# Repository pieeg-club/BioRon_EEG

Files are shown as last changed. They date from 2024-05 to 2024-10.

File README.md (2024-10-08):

# Open-source active electrode for biodata measurement of EEG, EMG,  etc. BioRon_EEG from PiEEG

<p align="center">
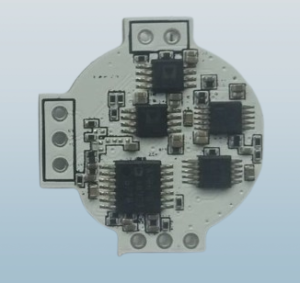
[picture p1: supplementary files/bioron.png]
generals view
  
</p>

### Low noise power supply, 2 stage Amplifier, Driven Right Leg, Band-Pass Filter, and ADC in one small board       

Our project aims to democratize the field of electroencephalography (EEG) by developing and sharing open-source designs for active EEG electrodes. EEG is a powerful technique for monitoring brain activity, but the cost and complexity of traditional EEG equipment have limited its accessibility. We're here to change that!  
 
Our repository hosts detailed schematics, and layouts for creating active EEG electrodes. Whether you're a hardware enthusiast or a researcher, you can find everything you need to build your own electrodes from scratch.  

### Contributing:       
Whether you're an electronics wizard, a software guru, a neuroscience enthusiast, or just curious, your contributions are welcome! 

### Our Vision:      
By providing open-source active EEG electrode designs, we're fostering collaboration, innovation, and knowledge sharing in the fields of neuroscience, bioengineering, and beyond. Our goal is to make high-quality EEG technology accessible to researchers, students, hobbyists, and clinicians worldwide, enabling a deeper understanding of the human brain and its functions. 

Join us in PiEEG mission to revolutionize EEG technology and make a significant impact on brain research! Feel free to reach out, contribute, and be part of the EEG revolution. 

### Contact:
Email: pieeg@pieeg.com  
Website: https://pieeg.com/    

Paper    
https://www.preprints.org/manuscript/202409.1703/v1    
Cite as: 
rakhmatulin, I. A Novel Tiny Open-Source Board BioRon_EEG for Dry Active Electrode. Preprints 2024, 2024091703. https://doi.org/10.20944/preprints202409.1703.v1

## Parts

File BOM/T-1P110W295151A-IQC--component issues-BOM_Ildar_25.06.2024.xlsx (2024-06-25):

T-1P110W295151A-BOM清单
No. Item | 捷创ID | 型号 Mfg Part | 封装 Package/Footprint | 规格参数 Description / Value | 位号 Designator | 单板用量 Qty per board | 总量 Total Qty | 来料数量 Qty Received | 物料备注 Instructions / Notes | 不良原因 Assembly Question | 是否全部空贴 | 是否少料空贴 | 是否按来料贴 | 是否等补料 | 客户回复 Reply from Customer
1 | W202830-001 | ADS1115IDGSR |  | ADS1115IDGSR | U1.ads1115 | 1 | 1 | 1
2 | W202830-002 | ad8618ad2086429 https://www.mouser.co.uk/ProductDetail/Analog-Devices/AD8618ARUZ-REEL?qs=%2FtpEQrCGXCyqKNk0uxY9fw%3D%3D | SOP65P640X120-14N |  | U2.ad8618 | 1 | 1 | 1 |  | As shown in picture, component is bigger than pads on the board. It can't be soldered. Please check and reply. Repalce for ad8618ad2086429
3 | W202830-003 | AD8220WARMZ |  | AD8220WARMZ | U3.AD8220 | 1 | 1 | 1
4 | W202830-004 | OPA2320SAIDGSR | SOP50P490X110-10N |  | U4.OPA-2320 | 1 | 1 | 1 |  | As shown in picture, component is bigger than pads on the board. It can't be soldered. Please check and reply. Replace for OPA2320SAIDGSR
5 | W202830-005 | OP2177ARMZ-R7 | MSOP-8 |  | U5.OP2177 | 1 | 1 | 1 |  | As shown in picture, component is bigger than pads on the board. It can't be soldered. Please check and reply. Replace for OP2177ARMZ-R7
6 | W202830-006 | LT3042IMSE#PBF | MSOP-10 |  | U1.1 | 1 | 1 | 1 |  | As shown in picture, component is bigger than pads on the board. It can't be soldered. And there is no pad in the center on the board. Please check and reply. Replace for LT3042IMSE#PBF
7 | W202830-007 | LM2662MX/NOPB |  | LM2662M | U1.2 | 1 | 1 | 1 |  | As shown in picture, component is bigger than pads on the board. It can't be soldered. Please check and reply.
8 | W202830-008 | LT3094IMSE#PBF |  | LT3094IMSE#PBF | U1.3 | 1 | 1 | 1 |  | As shown in attached screenshot, there is no pad on the board in thecenter .Should we solder what we received? Yes, please solder
9 | W202830-009 | RC0402FR-0710KL | 0402 | RES 10K OHM 1/8W (also acceptable 1/16W) 1% 0402 SMD | R1.1,R1.5,R1.27,R1.28,R1.29 | 5 | 5 | 10 | 1/16W
10 | W202830-010 | RC0402FR-0724K9L | 0402 | RES 24.9K OHM 1/8W (also acceptable 1/16W) 1% 0402 SMD (or the most close nominal) | R1.2,R1.7,R1.8 | 3 | 3 | 10 | 1/16W
11 | W202830-011 | RC0402FR-0733K2L | 0402 | RES 33.2 K OHM 1/8W (also acceptable 1/16W) 1% 0402 SMD (or the most close nominal) | R1.3,R1.18 | 2 | 2 | 10 | 1/16W
12 | W202830-012 | RC0402FR-0715KL | 0402 | RES 15K OHM 1/8W (also acceptable 1/16W) 1% 0402 SMD | R1.4,R1.6 | 2 | 2 | 10 | 1/16W
13 | W202830-013 | RC0402FR-074K12L | 0402 | RES 4.12K OHM 1/8W (also acceptable 1/16W) 1% 0402 SMD | R1.9 | 1 | 1 | 10 | 1/16W
14 | W202830-014 | RC0402FR-071KL | 0402 | RES 1K OHM 1/8W (also acceptable 1/16W) 1% 0402 SMD | R1.10,R1.13 | 2 | 2 | 10 | 1/16W
15 | W202830-015 | RC0402FR-074K02L | 0402 | RES 4K OHM 1/8W (also acceptable 1/16W) 1% 0402 SMD | R1.11,R1.12 | 2 | 2 | 10 | 4.02K 0402 1/16W，please confirm | What we purchased is RC0402FR-074K02L. It is 4.02K ohm,is it okay for you?You noted is 4Kohm. It is ok
16 | W202830-016 | RC0402FR-0712K7L | 0402 | RES 12.7K OHM 1/8W (also acceptable 1/16W) 1% 0402 SMD | R1.14 | 1 | 1 | 10 | 1/16W
17 | W202830-017 | RC0402FR-07499KL | 0402 | RES 499K OHM 1/8W (also acceptable 1/16W) 1% 0402 SMD | R1.15 | 1 | 1 | 10 | 1/16W
18 | W202830-018 | RC0402FR-07866KL | 0402 | RES 866K OHM 1/8W (also acceptable 1/16W) 1% 0402 SMD | R1.16 | 1 | 1 | 10 | 1/16W
19 | W202830-019 | RC0402FR-0713K3L | 0402 | RES 13.3K OHM 1/8W (also acceptable 1/16W) 1% 0402 SMD | R1.17,R1.21 | 2 | 2 | 10 | 1/16W
20 | W202830-020 | RC0402FR-0726K7L | 0402 | RES 26.7K OHM 1/8W (also acceptable 1/16W) 1% 0402 SMD | R1.19 | 1 | 1 | 10 | 1/16W
21 | W202830-021 | RC0402FR-078K25L | 0402 | RES 8.25K OHM 1/8W (also acceptable 1/16W) 1% 0402 SMD | R1.20 | 1 | 1 | 10 | 1/16W
22 | W202830-022 | RC0402FR-0726K1L | 0402 | RES 26.1K OHM 1/8W (also acceptable 1/16W) 1% 0402 SMD | R1.22 | 1 | 1 | 10 | 1/16W
23 | W202830-023 | RC0402FR-073K01L | 0402 | RES 3.01K OHM 1/8W (also acceptable 1/16W) 1% 0402 SMD | R1.23 | 1 | 1 | 10 | 1/16W
24 | W202830-024 | RC0402FR-079K31L | 0402 | RES 9.31K OHM 1/8W (also acceptable 1/16W) 1% 0402 SMD | R1.24 | 1 | 1 | 10 | 1/16W
25 | W202830-025 | RC0402FR-074K75L | 0402 | RES 4.75K OHM 1/8W (also acceptable 1/16W) 1% 0402 SMD | R1.25 | 1 | 1 | 10 | 1/16W
26 | W202830-026 | RC0402FR-070RL | 0402 | RES 0K OHM 1/8W (also acceptable 1/16W) 1% 0402 SMD | R1.26 | 1 | 1 | 10 | 1/16W ；规格不一致？
27 | W202830-027 | CL05A475MO5NUNC | 0402 | CAP CER 4.7μF 16V X7R (C0G) 0402 | C1.1,C1.2,C1.4,C1.5,C1.6,C1.7,C1.8,C1.10,C1.13,C1.15,C1.16,C1.31,C1.19,C1.21,C1.30,C1.33,C1.32 | 17 | 17 | 40 | 4.7uF 16V X5R 0402，please confirm
28 | W202830-028 | GRM155R71C474KE01D | 0402 | CAP CER 0.47μF 16V X7R (C0G) 0402 | C1.3 | 1 | 1 | 10 | 0.47uF 16V X7R 0402，please confirm
29 | W202830-029 | CC0402KRNPO7BN100 | 0402 | CAP CER 10pF 16V X7R (C0G) 0402 | C1.9 | 1 | 1 | 10 | 10pF 16V C0G 0402，please confirm
30 | W202830-030 | CC0402KRX7R7BB103 | 0402 | CAP CER 0.01μF 16V X7R (C0G) 0402 | C1.11,C1.12,C1.17,C1.14,C1.18,C1.20,C1.29 | 7 | 7 | 20 | 0.01uF 16V X7R 0402，please confirm
31 | W202830-031 | CC0402JRNPO9BN680 | 0402 | CAP CER 68pF 16V X7R (C0G) 0402 | C1.22 | 1 | 1 | 10 | 68pF 50V C0G 0402，please confirm
32 | W202830-032 | CL05A105KO5NNNC | 0402 | CAP CER 1μF 16V X7R (C0G) 0402 | C1.24,C1.23,C1.25,C1.26,C1.27,C1.28 | 6 | 6 | 20 | 1uF 16V X5R 0402，please confirm
33 | W202830-033 | 16-213/GHC-YR1S1/3T | 0402 | 16-213/GHC-YR1S1/3T | D1.1,D1.2,D1.3 | 3 | 3 | 10
IQC备注

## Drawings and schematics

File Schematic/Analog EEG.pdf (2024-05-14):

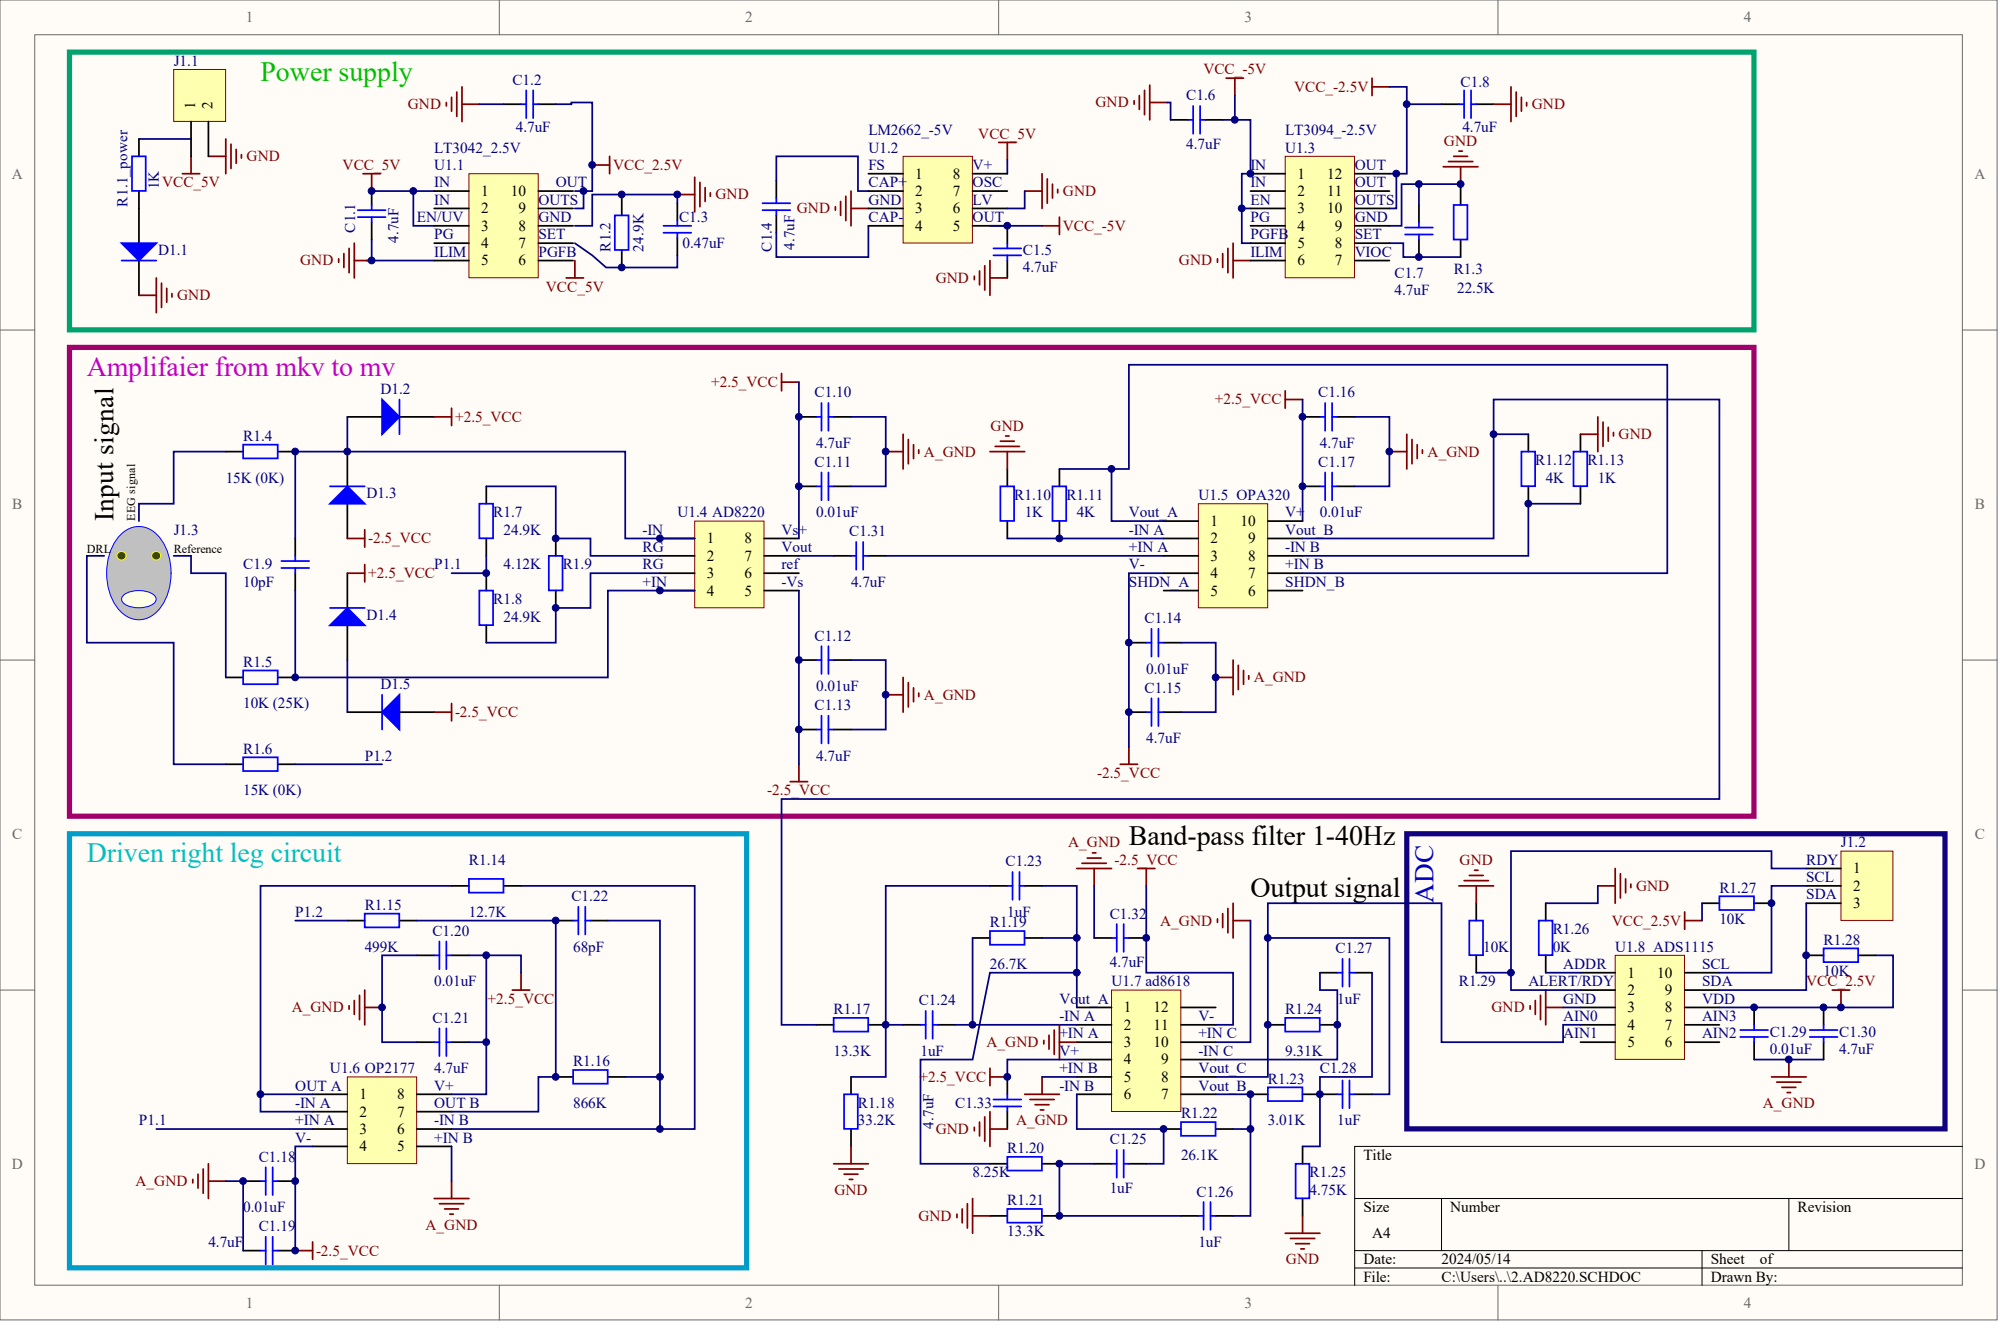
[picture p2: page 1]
Date:; Sheet of; File:; C:\Users\..\2.AD8220.SCHDOC; Drawn By:; OUT B; OUT A; -2.5_VCC 4.7uF; U1.5 OPA320; Vout_B; Power supply; Driven right leg circuit; Band-pass filter 1-40Hz; Output signal; G sig; U1.8 ADS1115; P0R1010power01 P0R1010power02; P0U105 OPA32001; P0U105 OPA32002; P0U105 OPA32003; P0U105 OPA32004; P0U105 OPA32005; P0U105 OPA32006; P0U105 OPA32007; P0U105 OPA32008; P0U105 OPA32009; P0U108 ADS111501; P0U108 ADS111502; P0U108 ADS111503; P0U108 ADS111504; P0U108 ADS111505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

Amplifaier from mkv to mv
